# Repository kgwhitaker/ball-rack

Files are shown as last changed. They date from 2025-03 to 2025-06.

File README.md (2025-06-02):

# Ball Rack

Generalized Ball Holder

This will build a 3D model to hold balls of various diameters worthy of realizing on your 3D Printer. I have used this model to
create a holder for wool dryer balls that fastens to the wall and lacrosse balls that sits on a table in the exercise room.

## Model Parameters

| Parameter | Description |
| --- | --- |
| ball_diameter | Diameter of the ball in millimeters. Include spacing so that it is not too tight. |
| balls_per_column | Number of balls to hold in each column. |
| columns | Number of columns in the ball holder. |
| trim_top_pct | Percentage of a single ball to trim off the top of the ball rack. This is to let the top of the ball show out the top or help it fit within the maximum Z of your printer. |
| screw_mount | Set to false if you do not want to have the keyhole screw mounts for the model. |
| screw_head_diameter  | Screw head diameter in millimeters for the mounting screw. |
| screw_shaft_diameter | Screw shaft diameter in millimeters for the mounting screw. |
| feeder | If true, the ball holder will have a ball feeder at the bottom. Otherwise the balls need to be pulled from the top. |
| side_cutouts | Set to true to put cutouts on the sides of the holder to reduce filament use. |

## Realized Models

The `models` folder contains generated STL files that you can print on your 3D printer.  My use case was for lacrosse balls in my 
exercise room and wool dryer balls in our laundry room.  I have generated various configurations with the following naming 
conventions:

- `*-dryer-80mm-*`: is for a wool dryer ball of 80mm with tolerance.
- `*-lacross-64mm-*`: is for a lacrosse ball.
- `*-feeder-*`: the rack has a feeder at the bottom.
- `*-2col*`: The rack has two columns.
- `*-screw-mount-*`: There are keyholes for mounting the ball rack.

Also in the `models` folder is `*.3mf` files.  These are [Orca Slicer](https://orcaslicer.com) project files that I used.  
`*-a1mini.3mf` project file is for a Bambu Lab A1 mini.  `*-mk3.3mf` is for a Prusa MK3S+ printer.

## Dependencies and Building

This model is built using the tools listed below. Install these tools and you can open up the SCAD file
in this repo to create your own printable object.  Once installed, you can use the _Customizer_ UI in OpenSCAD 
to modify the model to fit your needs.  I do recommend installing the [development snapshot of OpenSCAD](https://openscad.org/downloads.html#snapshots) 
for the best experience.

- [OpenSCAD](https://openscad.org)
- [The Belfry OpenScad Library, v2.0.](https://github.com/BelfrySCAD/BOSL2)

## Example Output

### Two Column Dryer Ball Rack

Parameters used:

```
ball_diameter = 80;
balls_per_column = 2;
columns = 2;
trim_top_pct = 0.50;
screw_head_diameter = 12;
screw_shaft_diameter = 6;
feeder = true;
feeder_scale = 1;
side_cutouts = false;
screw_mount = true;
```

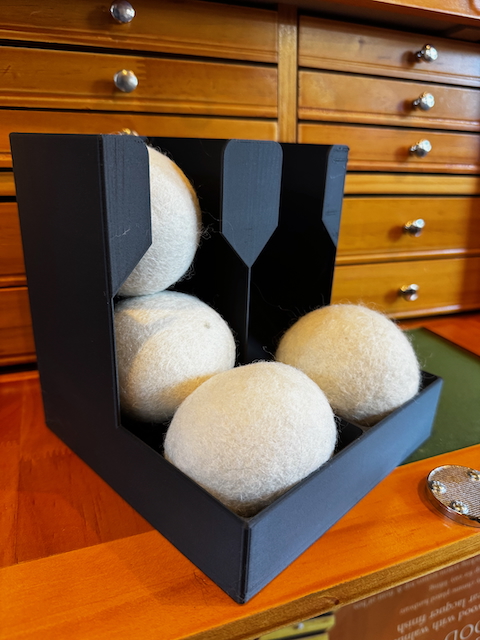
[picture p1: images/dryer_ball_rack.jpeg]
Wool Dryer Ball Rack Example


### One Column Dryer Ball Rack

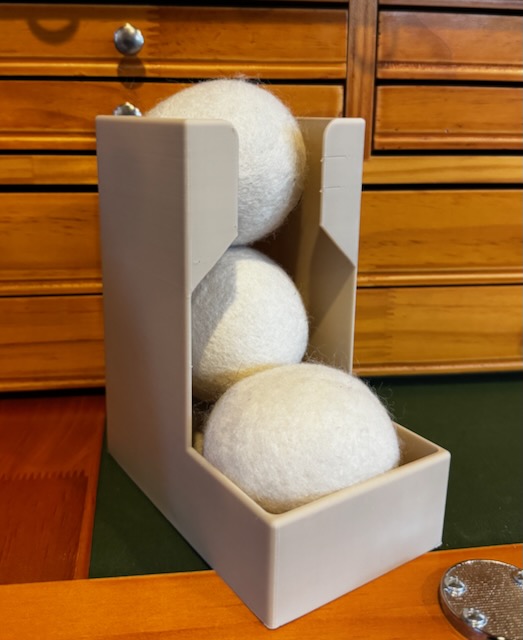
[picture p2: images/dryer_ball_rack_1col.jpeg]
1 Column Wool Dryer Ball Rack


### Lacrosse Ball Rack with Feeder Tray

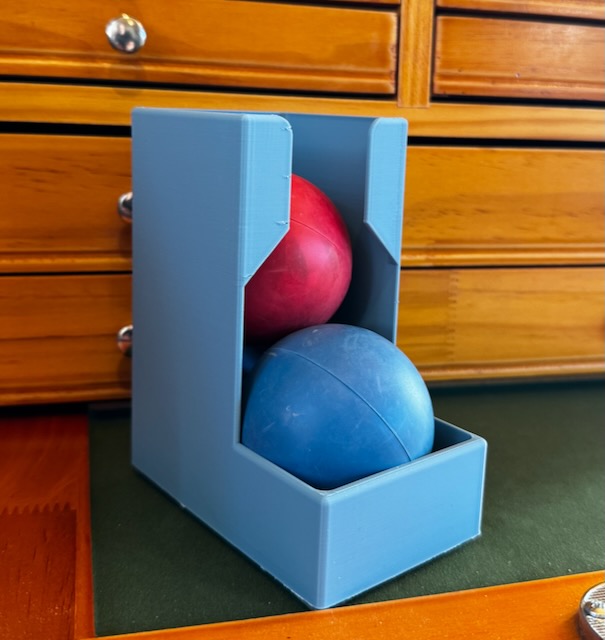
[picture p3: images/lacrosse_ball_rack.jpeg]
Lacrosse Ball Rack Example


### Lacrosse Ball Rack with no Feeder Tray

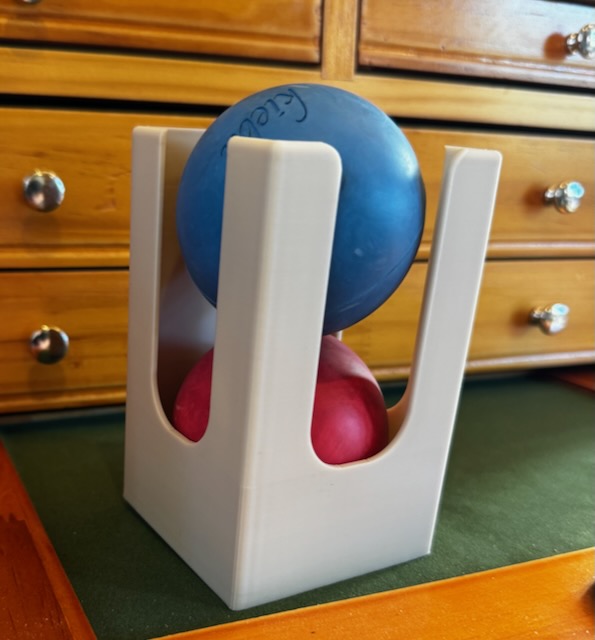
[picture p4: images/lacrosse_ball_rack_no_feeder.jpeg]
Lacrosse Ball Rack with no Feeder Tray


### Optional Screw Holes

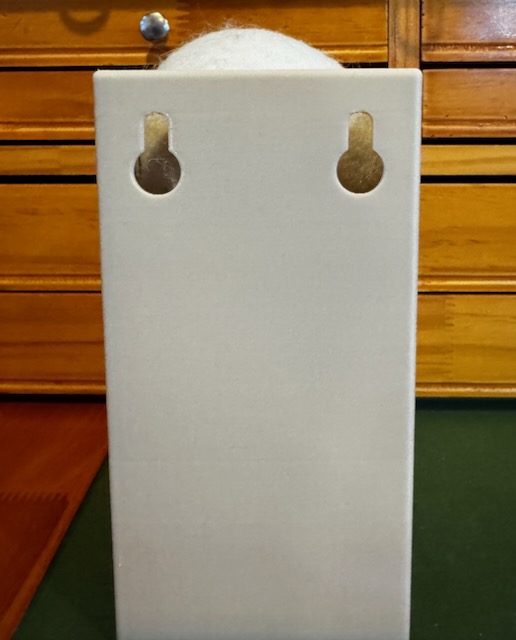
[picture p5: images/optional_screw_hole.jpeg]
Optional Screw Holes


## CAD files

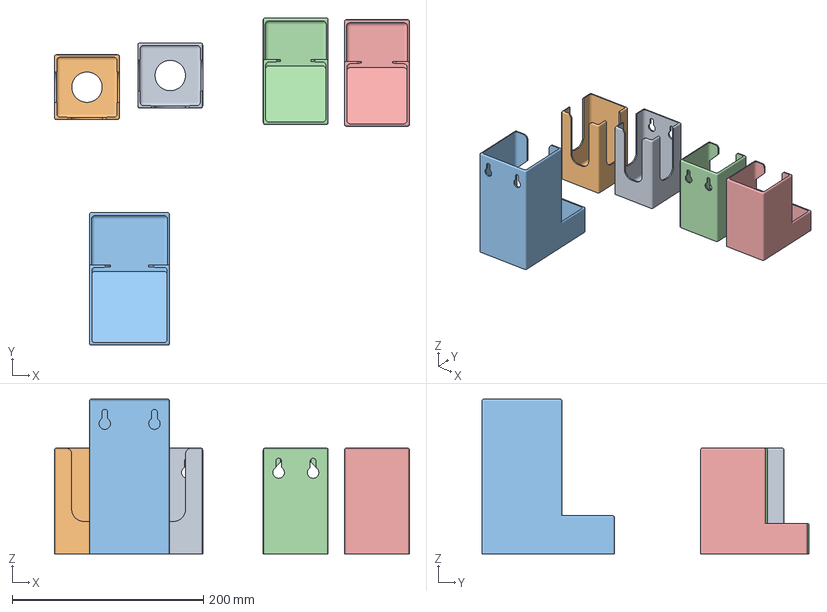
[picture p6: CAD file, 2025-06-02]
models/ball-rack-a1mini.3mf
371.5 x 342.5 x 162.0 mm
ball-rack-lacrosse-64mm-no-feeder-screw-mount.stl
ball-rack-lacrosse-64mm-no-feeder.stl
ball-rack-dryer-80mm-feeder-x2-screw-mount.stl
ball-rack-lacrosse-64mm-feeder-screw-mount.stl
ball-rack-lacrosse-64mm-feeder.stl

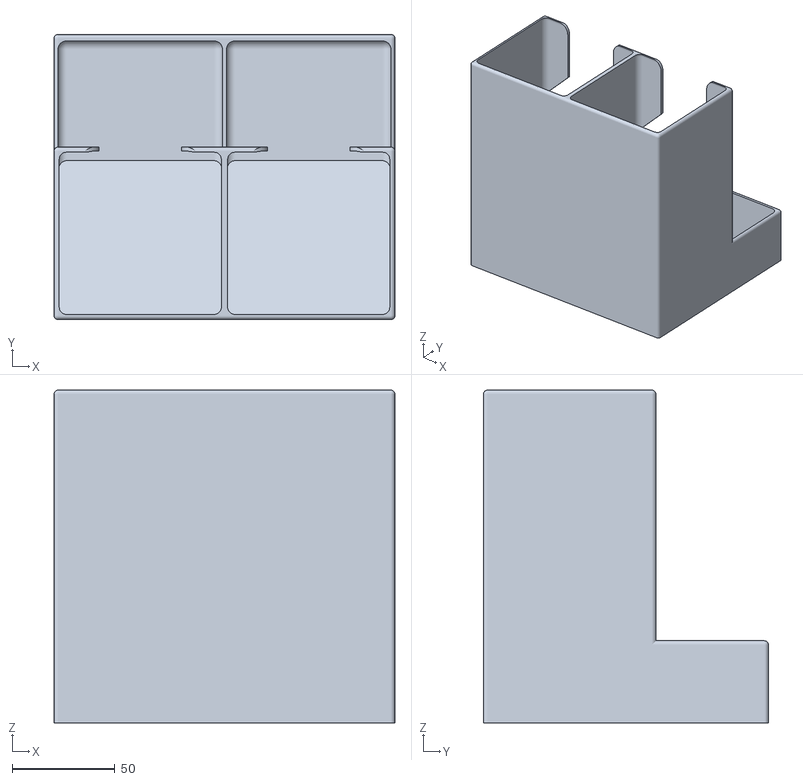
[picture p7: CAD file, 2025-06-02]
models/ball-rack-dryer-80mm-feeder-2col.stl
166.0 x 138.8 x 162.0

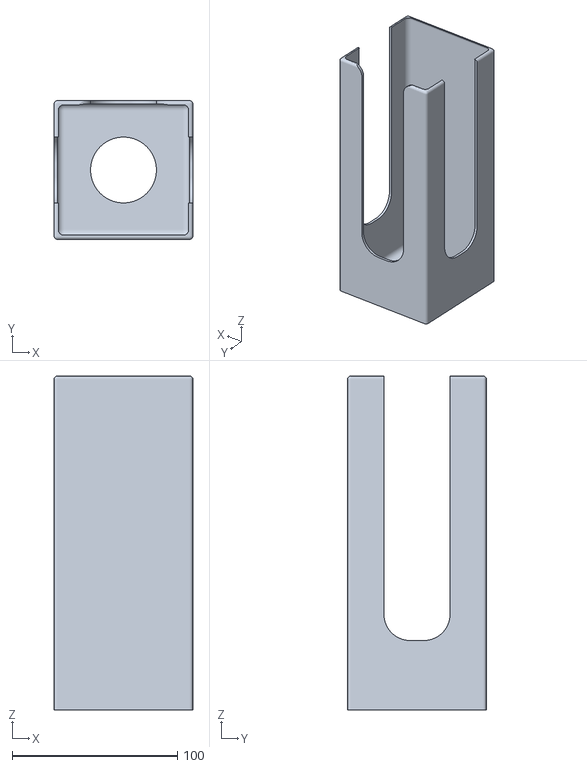
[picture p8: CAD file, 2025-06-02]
models/ball-rack-dryer-80mm-no-feeder.stl
84.0 x 84.0 x 202.0

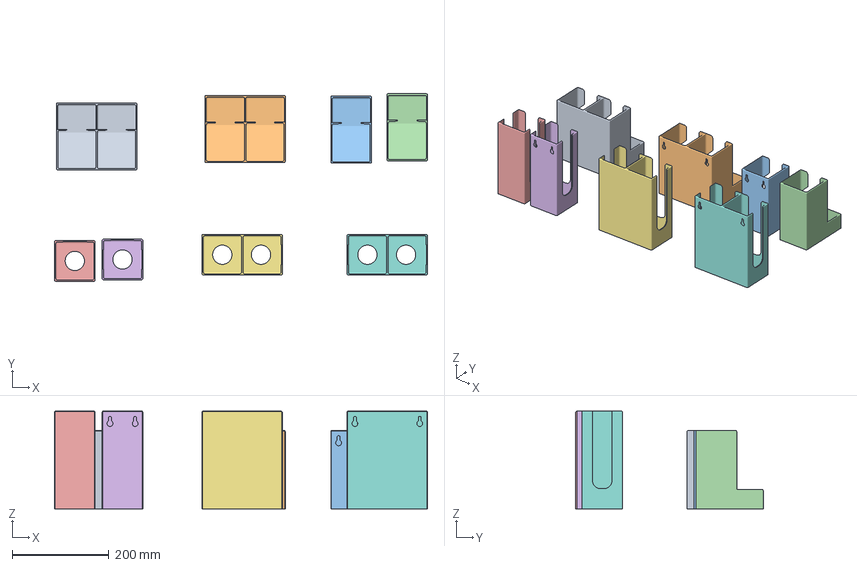
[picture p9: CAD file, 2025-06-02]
models/ball-rack-mk3.3mf
771.2 x 387.8 x 202.0 mm
ball-rack-dryer-80mm-feeder-2col.stl
ball-rack-dryer-80mm-feeder-2col-screw-mount.stl
ball-rack-dryer-80mm-feeder-screw-mount.stl
ball-rack-dryer-80mm-feeder.stl
ball-rack-dryer-80mm-no-feeder.stl
ball-rack-dryer-80mm-no-feeder-screw-mount.stl
ball-rack-dryer-80mm-no-feeder-2col.stl
ball-rack-dryer-80mm-no-feeder-2col-screw-mount.stl

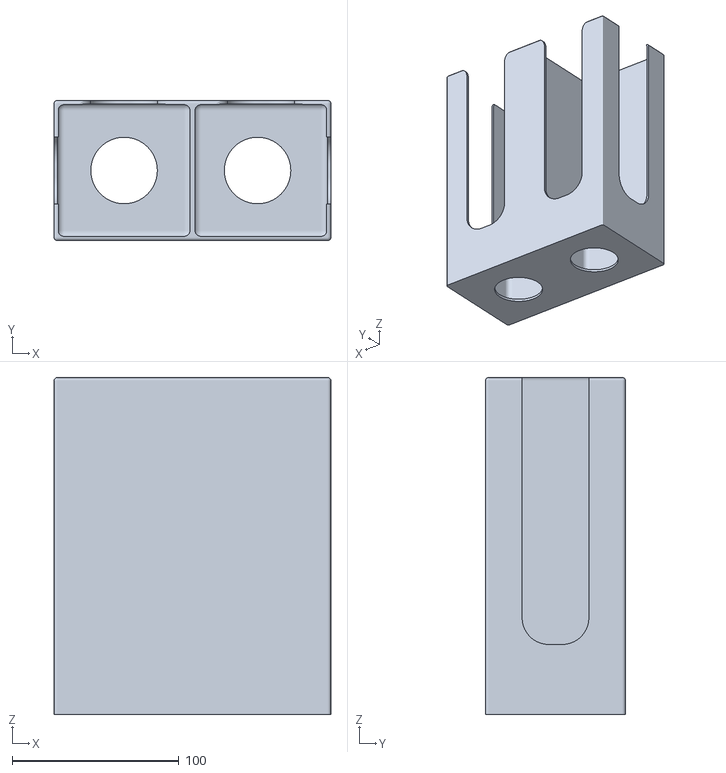
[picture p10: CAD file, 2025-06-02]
models/ball-rack-dryer-80mm-no-feeder-2col.stl
166.0 x 84.0 x 202.0

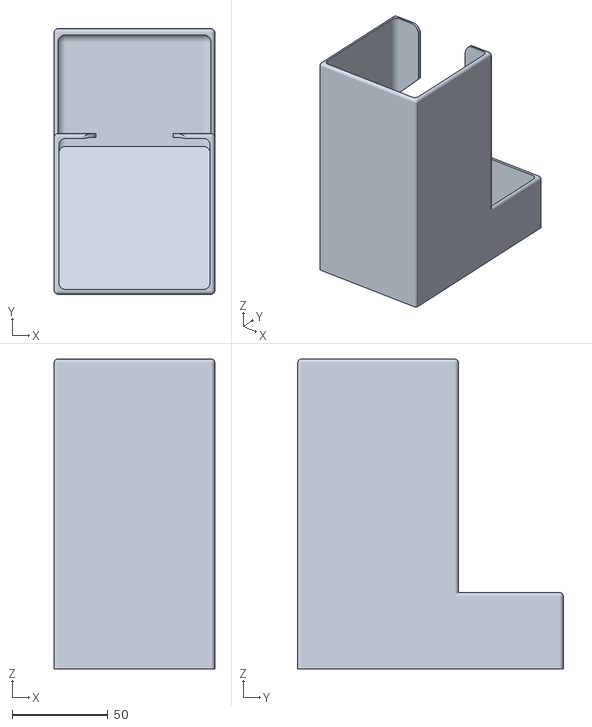
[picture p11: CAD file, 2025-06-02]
models/ball-rack-dryer-80mm-feeder.stl
84.0 x 138.8 x 162.0

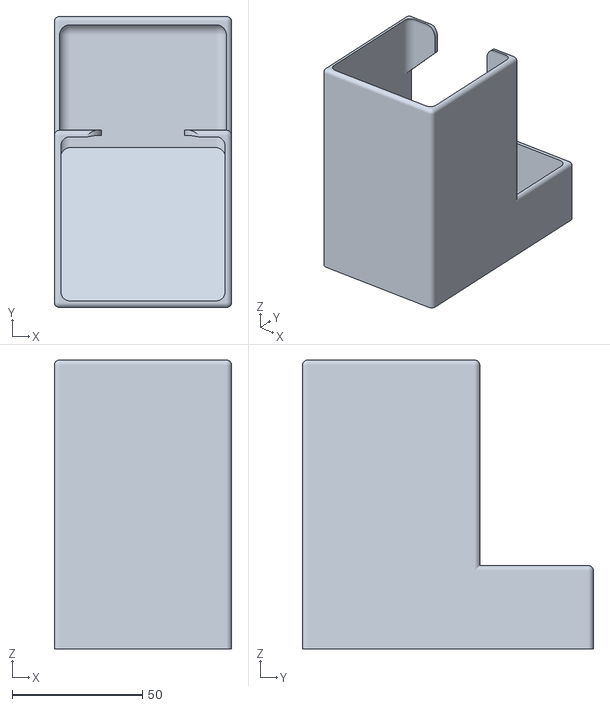
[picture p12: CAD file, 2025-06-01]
models/ball-rack-lacrosse-64mm-feeder.stl
68.0 x 111.6 x 110.8

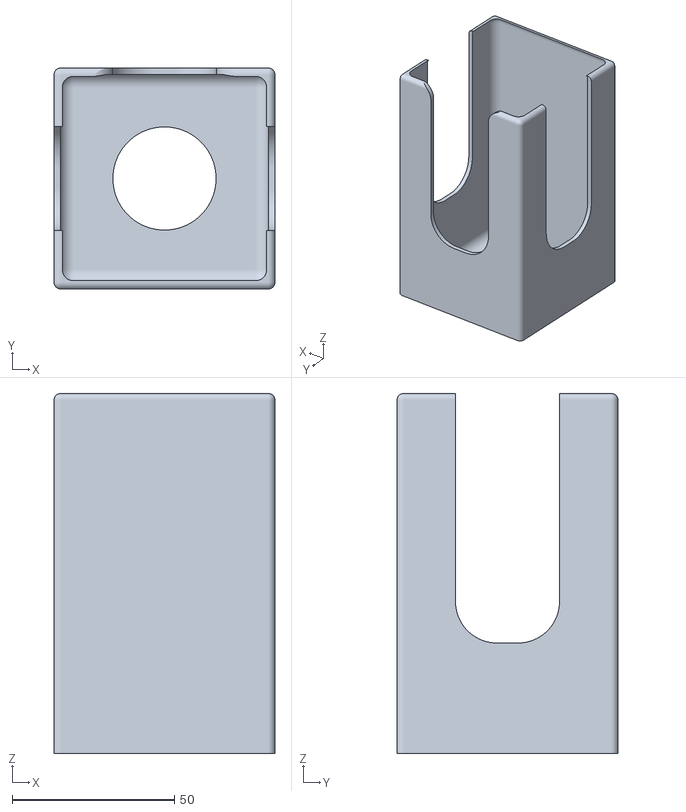
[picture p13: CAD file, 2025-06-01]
models/ball-rack-lacrosse-64mm-no-feeder.stl
68.0 x 68.0 x 110.8

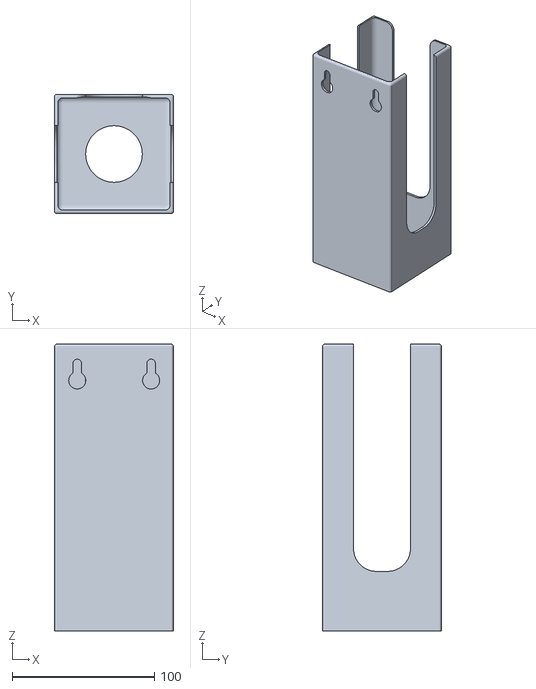
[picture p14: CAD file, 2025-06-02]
models/ball-rack-lacrosse-64mm-no-feeder-screw-mount.stl
84.0 x 84.0 x 202.0

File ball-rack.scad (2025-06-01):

//
// A holder for balls. Wool Dryer Balls.  Lacrosse Balls.  Whatever balls you want to hold. 
//

// The Belfry OpenScad Library, v2:  https://github.com/BelfrySCAD/BOSL2
include <BOSL2/std.scad>

// *** Model Parameters ***
/* [Model Parameters] */

// Diameter of the ball in millimeters.  Include spacing so that it is not too tight.
// 64mm for a lacrosse ball, 80mm for a wool dryer ball.
ball_diameter = 64;

// Number of balls to hold in each column.
balls_per_column = 2;

// Number of columns
columns = 1;

// Thickness of the walls for the holder.
wall_thickness = 2;

// Percentage of a single ball to trim off the top of the ball rack.
// This is to let the top of the ball show out the top, and lets a 
// three ball rack fit in a 210mm tall printer.
// 0.50 = 50% of the ball diameter.  0=Ball is fully enclosed.
trim_top_pct = 0; // [0:0.1:1]

// Set to true to put cutouts on the sides of the holder.
side_cutouts = true;

/* [Feeder Tray] */

// If true, the ball holder will have a ball feeder at the bottom.
// Otherwise the balls need to be pulled from the top.
feeder_tray = false;

//
// Scale for the feeder tray, if desired.  This will make the catch tray 
// a percentage of the ball diameter.  I think the aesthetics are better if the catch 
// tray is less than the diameter of the ball.  1=No scaling.
feeder_scale = 0.6; // [0.1:0.1:1]

/* [Screw Mount] */

// Keyhole for screw mounting of the ball holder.
screw_mount = false;

// Screw Head Diameter for the mounting screw.
screw_head_diameter = 12;

// Screw Shaft Diameter for the mounting screw.
screw_shaft_diameter = 6;

// *** "Private" variables ***
/* [Hidden] */

// OpenSCAD System Settings
$fa = 1;
$fs = 0.4;

// *** Calculated Global Vars *** 

// Radius of the notch cutout curved edges.  Calculate at 20% of the ball diameter.
notch_radius = ball_diameter * 0.20;

// Number of walls to accommodate the columns
walls = (columns - 1) + 2;

// Radius of the fillets for the outer edges of the holder.
fillet_radius = 2;

// Overall dimensions width of the holder
width = (walls * wall_thickness) + (ball_diameter * columns);
height = (balls_per_column * ball_diameter) - (ball_diameter * trim_top_pct) + wall_thickness; // 1 wall at the bottom
depth = ball_diameter + (wall_thickness * 2); // front and back walls. 

// Width of the cutouts on the sides.  1/2 of the ball diameter.
notch_width = (ball_diameter / 2); 

// Put a hole in the bottom to reduce filament use and center the ball in the holder.
//
// Parameters:
//
// column - The column number of the ball rack to place the hole in.
//
module bottom_hole(column = 0) {
    hole_diameter = ball_diameter / 2; 
    translate([
        (column * (ball_diameter) + (ball_diameter / 2)) + wall_thickness, 
        (ball_diameter / 2) + wall_thickness, 
        0]) {

        sphere(r = hole_diameter / 2);
    }
}

// 
// Notch on the outer edge of the holder.
//
// Parameters:
//
// x_pos - The x position of the notch.
//
module outer_notch(x_pos) {
    translate([
        x_pos, 
        (ball_diameter / 2) - (notch_width / 2) + wall_thickness, 
        notch_width + wall_thickness]) 
        {
            cuboid([2 * wall_thickness, notch_width, balls_per_column * ball_diameter], 
                anchor=FRONT+LEFT+BOT, rounding=notch_radius, edges=[BOT], except=[LEFT, RIGHT]);
        }
}

//
// Screw Keyhole for hanging the holder.
//
// Parameters:
//
// x_pos - The x position of the notch.
//
module screw_hole(x_pos) {
    translate([
        x_pos, 
        -(wall_thickness / 2), 
        height - (screw_head_diameter * 2.5)]) 
        {
            screw_keyhole(screw_head_diameter, screw_shaft_diameter, (wall_thickness * 2), TOP+LEFT);
        }
}

// 
// Notch for the front of the holder.
//
// Parameters:
//
// column - The column number of the ball rack to place the notch in.
// rounded - If true, round the edges on the bottom of the notch.
//
module front_notch(column = 0, rounded = true) {
    relative_z = notch_width + wall_thickness; 
    translate([
        (((ball_diameter + wall_thickness) * column) + (notch_width / 2) + wall_thickness),
        ball_diameter - wall_thickness,
        relative_z])
    {
        if (rounded) {
            cuboid([notch_width, 4 * wall_thickness, height], 
                anchor=FRONT+LEFT+BOT, rounding=notch_radius, edges=[BOT], except=[FRONT, BACK]);
        } else {
            cuboid([notch_width, 4 * wall_thickness, height], 
                anchor=FRONT+LEFT+BOT);
        }

        // Rounds the top corners of the notch
        translate([0,0,relative_z]) {
            // the 0.1 addition to the height is to handle rounding errors that were causing a very thin bridge.
            cuboid([notch_width, 4 * wall_thickness, height - (relative_z * 2) + 0.1], anchor=FRONT+LEFT+BOT, rounding=-(notch_radius / 2), edges=[TOP], except=[FRONT, BACK]);
        }         
    }
}

// 
// Creates a ramp for the feeder tray.
// 
// Parameters:
//
// column - The column number of the ball rack to place the notch in.
//
module feeder_ramp(column = 0) {
    translate([column * (ball_diameter + wall_thickness) + wall_thickness,
        ball_diameter,
        0]) {
        rotate([0, 0, -90]) {
            prismoid(
                size1=[ball_diameter,ball_diameter], 
                size2=[0,ball_diameter], 
                shift=[(ball_diameter / 2),0], 
                h=(ball_diameter * 0.75), 
                anchor=BOT+LEFT+FRONT
                );
        }
    }
}

//
// Creates the feeder catcher tray.
//
module feeder_tray() {    
    translate([0,ball_diameter,0]) {
        cuboid([width, depth * feeder_scale, (ball_diameter / 2)], anchor=FRONT+LEFT+BOT, rounding=fillet_radius,  except=BOT);
    }
}

//
// Feeder "tube" for the feeder tray. Cutout from the column into the front feeder tray.
//
// Parameters:
//
// column - The column number of the ball rack to place the notch in.
//
module feeder_tube(column = 0) {

    // bottom part of cutout using rounded corners.
    translate(
        [column * (wall_thickness + ball_diameter) + wall_thickness, 
        ball_diameter - (wall_thickness * 3), 
        wall_thickness]) {

            // the 0.1 in the height is to force an overlap of the bottom half and the top half of the cutout.
            cuboid([ball_diameter, ((ball_diameter + (wall_thickness * 4)) * feeder_scale), ((ball_diameter / 2) - wall_thickness + 0.1)], 
                anchor=FRONT+LEFT+BOT, 
                rounding=(fillet_radius * 2),   
                except=[FRONT, TOP]);
        }

    // Top part of the cutout using a chamfer at the top to avoid overhangs when printing.
    translate(
        [column * (wall_thickness + ball_diameter) + wall_thickness, 
        ball_diameter - (wall_thickness * 3), 
        (ball_diameter / 2)]) {
            cuboid([ball_diameter, ball_diameter + (wall_thickness * 4), (ball_diameter * 1.25)], 
                anchor=FRONT+LEFT+BOT, 
                chamfer=(ball_diameter / 2),   
                except=[FRONT, BACK, BOT]);
        }

}

// 
// Creates a keyhole shape for a screw
//
// Parameters:
//
// screw_head_diameter: The diameter of the screw head
// screw_shaft_diameter: The diameter of the screw shaft
// keyhole_depth: The depth of the keyhole
// anchor: The anchor point for the keyhole.  See BOSL2/attachments.scad for anchor points.
//
module screw_keyhole(screw_head_diameter, screw_shaft_diameter, keyhole_depth, anchor) {
    rotate([-90, 0, 0]) {
        linear_extrude(height = keyhole_depth) {
            keyhole(l=screw_head_diameter, r1=(screw_head_diameter /2), r2=(screw_shaft_diameter / 2), anchor=anchor);
        }
    }
}


//
// Main function build the model in its entirety.
//
module build_model() {
    // Creates the overall ball holder.
    difference() {

        // Outer cube that defines the overall ball holder.
        union() {
            cuboid([width, depth, height], anchor=FRONT+LEFT+BOT, rounding=fillet_radius,  except=BOT);
            if (feeder_tray) feeder_tray();
        }   

        
        // Builds the columns of the ball holder.
        for (i = [0 : columns - 1]) {
        
            // Inner cube (hollow part). one for each row separated by a wall.   
            translate([(i * (ball_diameter + wall_thickness) + wall_thickness), 
                wall_thickness, wall_thickness]) {            
                cuboid([ball_diameter, ball_diameter, height], anchor=FRONT+LEFT+BOT, rounding=(fillet_radius * 2));
            }

            if (feeder_tray) {
                front_notch(i, false);
                feeder_tube(i);
            } else {
                // Notch in the front of the holder. Curved for the non-feeder version.
                front_notch(i, true);
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

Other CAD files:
models/ball-rack-dryer-80mm-feeder-2col-screw-mount.stl
models/ball-rack-dryer-80mm-no-feeder-2col-screw-mount.stl
models/ball-rack-dryer-80mm-no-feeder-screw-mount.stl
models/ball-rack-dryer-80mm-feeder-screw-mount.stl
models/ball-rack-lacrosse-64mm-feeder-screw-mount.stl

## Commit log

2025-01-07 Ported from old project. General cleanup.
    [ball-rack.scad, shapes_fun.scad]
2025-03-17 Added scaling factor for feeder tray
    [ball-rack.scad]
2025-06-01 Refactored to be Customizer UI friendly, fixed notch.
    [ball-rack.scad, shapes_fun.scad]
2025-06-01 Created 64mm models.
    [ball-rack-lacrosse-64mm-feeder-screw-mount.stl, ball-rack-lacrosse-64mm-feeder.stl, ball-rack-lacrosse-64mm-no-feeder-screw-mount.stl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]
2025-06-01 Updated README, generated realized models.
    [ball-rack-a1mini.3mf, ball-rack-dryer-80mm-feeder-2col-screw-mount.stl, ball-rack-dryer-80mm-feeder-2col.stl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]
2025-06-02 Updated readme. Updated realized models.
    [ball-rack-a1mini.3mf, ball-rack-dryer-80mm-feeder-x2-screw-mount.stl, ball-rack-dryer-80mm-feeder-x2.stl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]
2025-06-02 Fixed realized models; updated readme for 3mf projects
    [ball-rack-a1mini.3mf, ball-rack-dryer-80mm-feeder-2col-screw-mount.stl, ball-rack-dryer-80mm-feeder-2col.stl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]
